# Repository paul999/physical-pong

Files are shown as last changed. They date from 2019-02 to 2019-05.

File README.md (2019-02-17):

# physical-pong

Do you remember pong from a long time ago? Well, I did, and I decided to make a physical version of the game.

This is the code required to run on the arduino mega. You can find more information about this project on the site: www.physical-pong.com

# Installing

This code is written for a arduino mega. You will need the platformio editor if you want to have it work out of the box.
It won't work with the default arduino IDE out of the box, and this is not something I plan on supporting.

If you are using this code without the ramps board as suggested, please make sure to check the pins in config.h, otherwise it won't work. For instructions on how to use the default configuration, please read the information found at https://www.physical-pong.com/instructions/
In config.php you can also enable DEBUG mode, which does write debug statements into the Serial console for debugging. It is suggested to disable this if you don't need it.

Before compiling, make sure you set the correct processor in paltformio.ini, otherwise you won't be able to upload your code to your Arduino.

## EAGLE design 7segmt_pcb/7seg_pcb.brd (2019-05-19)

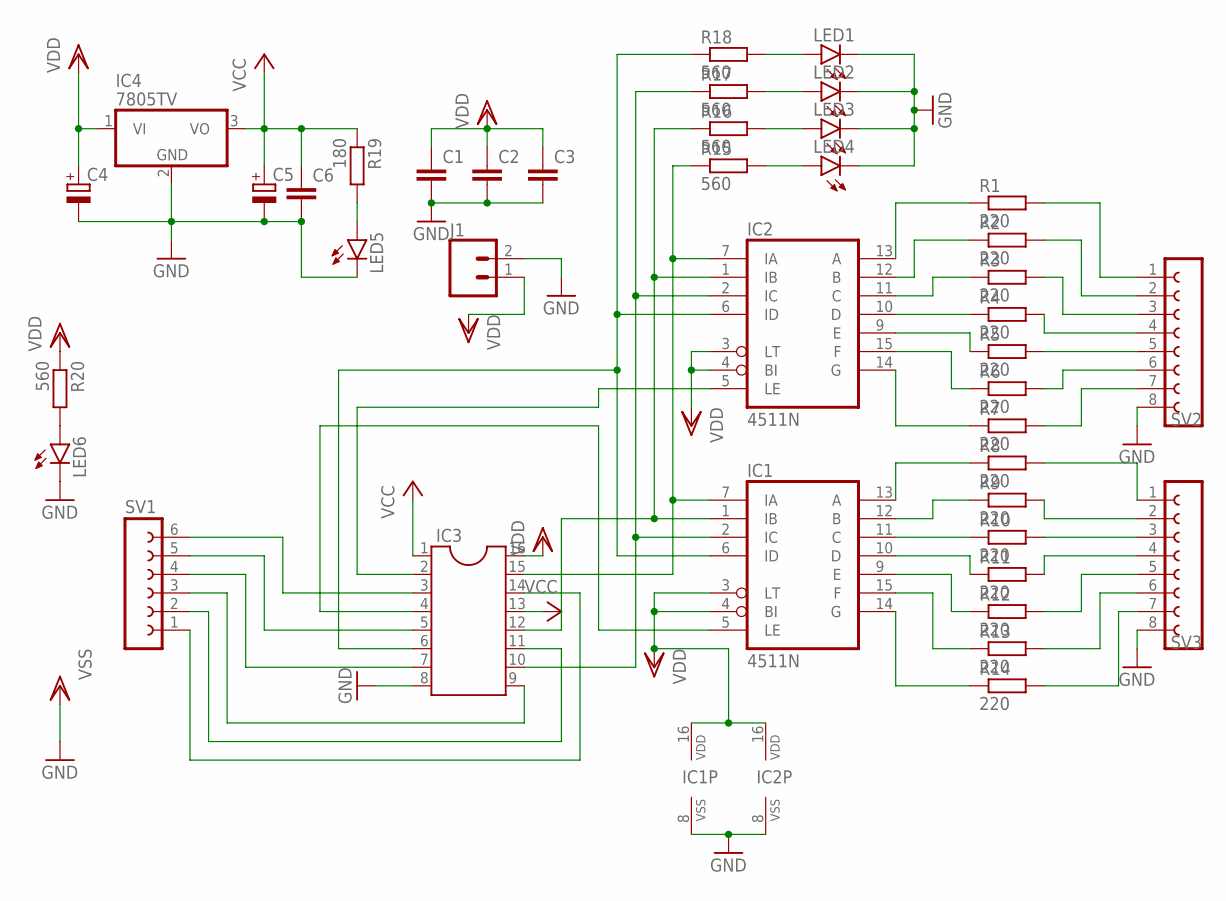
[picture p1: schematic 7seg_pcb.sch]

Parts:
C1, C2, C3, C6: C-EUC0805K; C0805K
C4, C5: CPOL-EUD; PANASONIC_D
IC1, IC2: 4511N; DIL16
IC3: DIL16S; SOCKET-16
IC4: 7805TV; TO220V
J1: CONN_025MM; SCREWTERMINAL-5MM-2
LED1, LED2, LED3, LED4, LED5, LED6: LEDCHIPLED_0805; CHIPLED_0805
R1, R2, R3, R4, R5, R6, R7, R8, R9, R10, R11, R12, R13, R14: 220; R0805
R15, R16, R17, R18, R20: 560; R0805
R19: 180; R0805
SV1: FE06-1; FE06
SV2, SV3: FE08-1; FE08

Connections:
GND: C1.2, C2.2, C3.2, C4.-, C5.-, C6.2, IC1.8 (VSS), IC2.8 (VSS), IC3.8, IC4.2 (GND), J1.2, LED1.C, LED2.C, LED3.C, LED4.C, LED5.C, LED6.C, SV2.8, SV3.8
unnamed: IC2.13 (A), R1.1
unnamed: IC2.12 (B), R2.1
unnamed: IC2.11 (C), R3.1
unnamed: IC2.10 (D), R4.1
unnamed: R14.2, SV3.7
unnamed: R13.2, SV3.6
unnamed: R12.2, SV3.5
unnamed: R11.2, SV3.4
unnamed: R10.2, SV3.3
unnamed: R9.2, SV3.2
unnamed: R8.2, SV3.1
unnamed: R7.2, SV2.7
unnamed: R6.2, SV2.6
unnamed: R5.2, SV2.5
unnamed: R4.2, SV2.4
unnamed: R3.2, SV2.3
unnamed: R2.2, SV2.2
unnamed: R1.2, SV2.1
unnamed: IC2.9 (E), R5.1
unnamed: IC2.15 (F), R6.1
unnamed: IC2.14 (G), R7.1
unnamed: IC1.13 (A), R8.1
unnamed: IC1.12 (B), R9.1
unnamed: IC1.11 (C), R10.1
unnamed: IC1.10 (D), R11.1
unnamed: IC1.9 (E), R12.1
unnamed: IC1.15 (F), R13.1
unnamed: IC1.14 (G), R14.1
unnamed: IC1.7 (IA), IC2.7 (IA), IC3.15, R15.1
unnamed: LED1.A, R18.2
unnamed: IC1.1 (IB), IC2.1 (IB), IC3.12, R16.1
unnamed: LED2.A, R17.2
unnamed: IC1.2 (IC), IC2.2 (IC), IC3.10, R17.1
unnamed: IC1.6 (ID), IC2.6 (ID), IC3.6, R18.1
unnamed: IC1.5 (LE), IC3.4
unnamed: IC3.3, SV1.6
unnamed: LED3.A, R16.2
unnamed: LED4.A, R15.2
unnamed: IC3.14, SV1.1
unnamed: IC3.11, SV1.2
unnamed: IC3.9, SV1.3
unnamed: IC3.7, SV1.4
unnamed: IC3.5, SV1.5
unnamed: LED5.A, R19.2
unnamed: IC2.5 (LE), IC3.2
unnamed: LED6.A, R20.2
VCC: C5.+, C6.1, IC3.1, IC3.13, IC4.3 (VO), R19.1
VDD: C1.1, C2.1, C3.1, C4.+, IC1.3 (LT), IC1.4 (BI), IC1.16 (VDD), IC2.3 (LT), IC2.4 (BI), IC2.16 (VDD), IC3.16, IC4.1 (VI), J1.1, R20.1

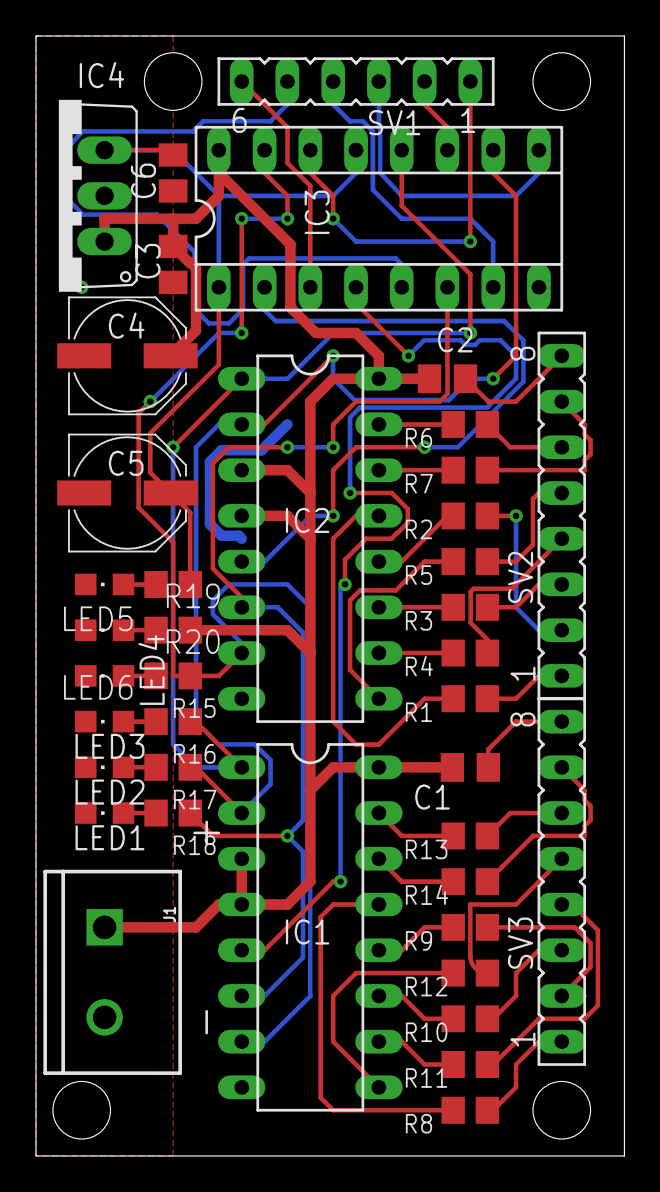
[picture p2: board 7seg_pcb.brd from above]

Board: 2 copper layers, 32.7 x 62.2 mm, 40 parts (0 on the bottom side), 49 nets.

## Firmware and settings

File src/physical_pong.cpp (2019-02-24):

/**
 * Copyright (C) 2019 by Paul Sohier
 * 
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
 * The above copyright notice and this permission notice shall be included in all copies or substantial portions of the Software.
 * 
 * THE SOFTWARE IS PROVIDED "AS IS", WITHOUT WARRANTY OF ANY KIND, EXPRESS OR IMPLIED, INCLUDING BUT NOT LIMITED TO THE WARRANTIES OF MERCHANTABILITY, 
 * FITNESS FOR A PARTICULAR PURPOSE AND NONINFRINGEMENT. IN NO EVENT SHALL THE AUTHORS OR COPYRIGHT HOLDERS BE LIABLE FOR ANY CLAIM, DAMAGES OR OTHER LIABILITY, 
 * WHETHER IN AN ACTION OF CONTRACT, TORT OR OTHERWISE, ARISING FROM, OUT OF OR IN CONNECTION WITH THE SOFTWARE OR THE USE OR OTHER DEALINGS IN THE SOFTWARE.
 */

#include "Arduino.h"
#include "config.h"
#include "motorControl.h"
#include "endstops.h"
#include "axis.h"
#include "log.h"

long player1_location = 0;
long player2_location = 0;
long short_axis_location = 0;
long long_axis_location = 0;
int mode = WAITING_FOR_START;
int current_long_direction = 0;
int current_short_direction = 0;

int short_last_change = 0;
int long_last_change = 0;
int steps_min_needed = 20; //ceil(STEPS_PER_MM * 3);

void setup()
{
  cli();
  Serial.begin(9600);
  logging("Starting up");
  setupPins();
  setupTimer();

  randomSeed(analogRead(0));

  logging("Startup done");

  disableMotor(false);

  logging("Going to start positions");

  player1_location = moveMotorToStart(aplayer1);
  player2_location = moveMotorToStart(aplayer2);

  logging("Moving axis");
  long_axis_location = moveMotorToStart(along);
  short_axis_location = moveMotorToStart(ashort);

  disableMotor(true);

  logging("Startup done. Now time to startup the loop");
}

void loop()
{
  if (mode == PLAYING)
  {
    digitalWrite(START_LED1, LOW);
    digitalWrite(START_LED2, LOW);
    // Time to do the actual movement.
    // But, only when we are still playing. (We might have just lost ;))
    if (mode == PLAYING)
    {
      movement mv;
      mv.along = HIGH;
      mv.ashort = HIGH;
      mv.aplayer1 = LOW;
      mv.aplayer2 = LOW;

      digitalWrite(LONG_AXIS_DIR, current_long_direction);
      digitalWrite(SHORT_AXIS_DIR, current_short_direction);
      int p1 = 0;
      int p2 = 0;

      if (digitalRead(PLAYER1_LEFT) == HIGH && readStop(aplayer1, start) == MISSED)
      {
        digitalWrite(PLAYER1_DIR, HIGH);
        mv.aplayer1 = HIGH;
        p1 = -1;
      }
      else if (digitalRead(PLAYER1_RIGHT) == HIGH && readStop(aplayer1, end) == MISSED)
      {
        digitalWrite(PLAYER1_DIR, LOW);
        mv.aplayer1 = HIGH;
        p1 = 1;
      }

      if (digitalRead(PLAYER2_LEFT) == HIGH && readStop(aplayer2, end) == MISSED)
      {
        digitalWrite(PLAYER2_DIR, LOW);
        mv.aplayer2 = HIGH;
        p2 = 1;
      }
      else if (digitalRead(PLAYER2_RIGHT) == HIGH && readStop(aplayer2, start) == MISSED)
      {
        digitalWrite(PLAYER2_DIR, HIGH);
        mv.aplayer2 = HIGH;
        p2 = -1;
      }
      moveSeveralMotorsOneStep(mv);

      player1_location = player1_location + p1;
      player2_location = player2_location + p2;
      long_axis_location = long_axis_location + (current_long_direction == HIGH ? 1 : -1);
      short_axis_location = short_axis_location + (current_short_direction == HIGH ? 1 : -1);

      // Check some of the locations we are at. We don't want negative locations and stuff.
      if (long_axis_location < 0)
      {
        long_axis_location = 0;
        logging("Warn: long axis went to < 0");
      }
      if (short_axis_location < 0)
      {
        short_axis_location = 0;
        logging("Warn: short axis went to < 0");
      }
      long_last_change++;
      if (long_last_change >= steps_min_needed)
      {
        if (readStop(along, start) == HIT || readStop(along, end) == HIT)
        {
          current_long_direction = current_long_direction == HIGH ? LOW : HIGH;
          logging("Something hit (LONG). Turning");
          long_last_change = 0;
        }
      }
      short_last_change++;
      if (short_last_change >= steps_min_needed)
      {
        if (readStop(ashort, start) == HIT || readStop(ashort, end) == HIT)
        {
          current_short_direction = current_short_direction == HIGH ? LOW : HIGH;
          logging("Something hit (SHORT). Turning");
          short_last_change = 0;
        }
      }

      if (readStop(aplayer1, start))
      {
        player1_location = 0;
      }
      if (readStop(aplayer2, start))
      {
        player2_location = 0;
      }
      if (player1_location < 0)
      {
        // We are at the begin. Set the location to 0
        player1_location = 0;
        logging("Warn: player1 axis went to < 0");
      }
      if (player2_location < 0)
      {
        // We are at the begin. Set the location to 0
        player2_location = 0;
        logging("Warn: player2 axis went to < 0");
      }
    }
  }
  else
  {
    digitalWrite(START_LED1, HIGH);
    digitalWrite(START_LED2, HIGH);

    if (digitalRead(START_BUTTON1) == HIGH || digitalRead(START_BUTTON2) == HIGH)
    {
      digitalWrite(START_LED1, LOW);
      digitalWrite(START_LED2, LOW);
      logging("User wants to start playing");
      mode = PLAYING;

      disableMotor(false);

      // Lets first move to start to get a good base point
      logging("Going to start now.");
      player1_location = moveMotorToStart(aplayer1);
      player2_location = moveMotorToStart(aplayer2);

      long_axis_location = moveMotorToStart(along);
      short_axis_location = moveMotorToStart(ashort);

      logging("Going to center position.");

      long loc = (PLAYER_LENGTH - (PLAYER_SIZE / 2l)) * STEPS_PER_MM;
      player1_location = moveMotorToLocation(aplayer1, loc, player1_location);
      player2_location = moveMotorToLocation(aplayer2, loc, player2_location);

      loc = (LONG_AXIS_LENGTH - (BLOCK_SIZE / 2l)) * STEPS_PER_MM;
      long_axis_location = moveMotorToLocation(along, loc, long_axis_location);

      loc = (SHORT_AXIS_LENGTH - (BLOCK_SIZE / 2l)) * STEPS_PER_MM;
      short_axis_location = moveMotorToLocation(ashort, loc, short_axis_location);

      // Decide to which directory we go to
      current_long_direction = (random(0, 500) % 2 == 0) ? HIGH : LOW;
      current_short_direction = (random(0, 500) % 2 == 0) ? HIGH : LOW;
      short_last_change = 0;
      long_last_change = 0;

      digitalWrite(LONG_AXIS_DIR, current_long_direction);
      digitalWrite(SHORT_AXIS_DIR, current_short_direction);

      disableMotor(true);
      // Lets get starting with warning the user that we are about to start ;)
      logging("Init done. Now lets warn the user");
      for (int i = 0; i < 10; i++)
      {
        digitalWrite(START_LED1, (i % 2 == 0) ? HIGH : LOW);
        digitalWrite(START_LED2, (i % 2 == 0) ? HIGH : LOW);
        delay(250);
      }
      digitalWrite(START_LED1, LOW);
      digitalWrite(START_LED2, LOW);
      disableMotor(false);
      logging("Lets get started");
    }
  }
}

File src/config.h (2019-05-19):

/**
 * Copyright (C) 2019 by Paul Sohier
 * 
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
 * The above copyright notice and this permission notice shall be included in all copies or substantial portions of the Software.
 * 
 * THE SOFTWARE IS PROVIDED "AS IS", WITHOUT WARRANTY OF ANY KIND, EXPRESS OR IMPLIED, INCLUDING BUT NOT LIMITED TO THE WARRANTIES OF MERCHANTABILITY, 
 * FITNESS FOR A PARTICULAR PURPOSE AND NONINFRINGEMENT. IN NO EVENT SHALL THE AUTHORS OR COPYRIGHT HOLDERS BE LIABLE FOR ANY CLAIM, DAMAGES OR OTHER LIABILITY, 
 * WHETHER IN AN ACTION OF CONTRACT, TORT OR OTHERWISE, ARISING FROM, OUT OF OR IN CONNECTION WITH THE SOFTWARE OR THE USE OR OTHER DEALINGS IN THE SOFTWARE.
 */

#ifndef __CONFIG_H__
#define __CONFIG_H__

// Enable debug mode. Will write stuff to serial for debugging
#define DEBUG false

// Enable calculation debug mode. Not suggested to enable, as it will cause
// issues with movements. Only enable it if you want to debug movement calculations
// Please note that enabling this flag will require you to press start when 
// the puck arrives at a start/stop on the long axis. 
// Make sure to read the serial output for information about the calculations and status!
#define DEBUG_CALC false

// Move to the start after a player is dead.
#define MOVE_TO_START true

// Shaft length for player/axis
// Make sure these sizes are correct, as they are used for a lot of calculations!
#define PLAYER_LENGTH 280
#define LONG_AXIS_LENGTH 480
#define SHORT_AXIS_LENGTH 280
#define STEPS_PER_MM 5

// Define the number of MM that is used for dead calculations.
#define MM_CALC 10

// Max number of games before we end
#define MAX_GAMES 10

// Begin/end stops for player bars
// X
#define PLAYER1_BEGIN   3
#define PLAYER1_END     2
// Z
#define PLAYER2_BEGIN   18
#define PLAYER2_END     19

// Begin/end stops for axis
// y
#define LONG_AXIS_BEGIN   14
#define LONG_AXIS_END     15
// AUX 2
#define SHORT_AXIS_BEGIN  16//65
#define SHORT_AXIS_END    17//66

// Motor settings for players
// X
#define PLAYER1_DIR   55//55
#define PLAYER1_STEP  54//54
#define PLAYER1_EN    38//38
// Y
#define PLAYER2_DIR   61//61
#define PLAYER2_STEP  60//60
#define PLAYER2_EN    56//56

// Motor settings for axis
// Z
#define LONG_AXIS_DIR   48
#define LONG_AXIS_STEP  46
#define LONG_AXIS_EN    62
// E
#define SHORT_AXIS_DIR  28
#define SHORT_AXIS_STEP 26
#define SHORT_AXIS_EN   24

// Buttons for going left/right with player pad
#define PLAYER1_LEFT  23
#define PLAYER1_RIGHT 25
#define PLAYER2_LEFT  27
#define PLAYER2_RIGHT 29    	

// Start button + start LED in button (Will light on when no game is active)
// Aux 1
#define START_BUTTON1  57
#define START_BUTTON2  58
// Heatbed connector
#define START_LED1     9
#define START_LED2     10

// Size of the player (Only width) blocks and actual block. Please keep in mind that the block should be square.
// Only change if you changed the 3D printed parts!
#define PLAYER_SIZE 45
#define BLOCK_SIZE 25

// Enable two 7 segment displays showing the current score. Make sure to set the correct pints below
#define ENABLE_SCORE_DISPLAY true
#define SEGMENT_A_PIN 31
#define SEGMENT_B_PIN 33
#define SEGMENT_C_PIN 35
#define SEGMENT_D_PIN 37
#define PLAYER1_LATCH_PIN 39
#define PLAYER2_LATCH_PIN 41

// Do not change after this line
#define PLAYING 1
#define WAITING_FOR_START 2
#define RESTARTING 3

#endif

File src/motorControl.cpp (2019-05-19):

/**
   Copyright (C) 2019 by Paul Sohier

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
   The above copyright notice and this permission notice shall be included in all copies or substantial portions of the Software.

   THE SOFTWARE IS PROVIDED "AS IS", WITHOUT WARRANTY OF ANY KIND, EXPRESS OR IMPLIED, INCLUDING BUT NOT LIMITED TO THE WARRANTIES OF MERCHANTABILITY,
   FITNESS FOR A PARTICULAR PURPOSE AND NONINFRINGEMENT. IN NO EVENT SHALL THE AUTHORS OR COPYRIGHT HOLDERS BE LIABLE FOR ANY CLAIM, DAMAGES OR OTHER LIABILITY,
   WHETHER IN AN ACTION OF CONTRACT, TORT OR OTHERWISE, ARISING FROM, OUT OF OR IN CONNECTION WITH THE SOFTWARE OR THE USE OR OTHER DEALINGS IN THE SOFTWARE.
*/

#include "Arduino.h"
#include "log.h"
#include "config.h"
#include "endstops.h"
#include "axis.h"
#include "motorControl.h"

int moveSequence(axis moveAxis)
{
  digitalWrite(getPin(stepPin, moveAxis), HIGH);
  delayMicroseconds(400);
  digitalWrite(getPin(stepPin, moveAxis), LOW);
  delayMicroseconds(400);

  if (readStop(moveAxis, end))
  {
    // Huh, we did hit a end?
    logging("We did hit a endstop?");
    return 1;
  }
  if (readStop(moveAxis, start))
  {
    logging("We did hit a start");
    return -1;
  }

  return 0;
}
void disableMotor(bool status)
{
  int st = status ? HIGH : LOW;
  digitalWrite(PLAYER1_EN, st);
  digitalWrite(PLAYER2_EN, st);
  digitalWrite(LONG_AXIS_EN, st);
  digitalWrite(SHORT_AXIS_EN, st);
}

long moveMotorToStart(axis moveAxis)
{
  if (readStop(moveAxis, start) == HIT)
  {
    // Motor is already in start Position.
    logging("Motor is at start");
    return 0;
  }
  digitalWrite(getPin(dirPin, moveAxis), HIGH);
  boolean atEnd = false;
  if (readStop(moveAxis, end) == HIT)
  {
    logging("Motor is at end");
    atEnd = true;
  }
  logging("Starting loop");

  long i = 0;

  while (true)
  {
    i++;
    if (i > 100000l)
    {
      // 200 steps per mm, max length is ~500mm. So 200 * 500: 100000 should always result in the start!
      logging("Unable to get to start");
      disableMotor(true);
      return -1;
    }
    if (!atEnd && readStop(moveAxis, end) == HIT)
    {
      logging("Looks like we hit a endstop while going to home. Wrongly configured?");
      logging("We will return now, but we are not in a save position!");
      disableMotor(true);
      return -1;
    }
    if (atEnd && readStop(moveAxis, end) == MISSED)
    {
      atEnd = false;
    }
    if (readStop(moveAxis, start) == HIT)
    {
      logging("Arrived at start :D");
      return 0;
    }
    digitalWrite(getPin(stepPin, moveAxis), HIGH);
    delayMicroseconds(400);
    digitalWrite(getPin(stepPin, moveAxis), LOW);
    delayMicroseconds(400);
  }
}

long moveMotorToLocation(axis moveAxis, long location, long currentLocation)
{
  logging("Moving to location");
  if (location == currentLocation)
  {
    return currentLocation;
  }
  if (location <= currentLocation)
  {
    digitalWrite(getPin(dirPin, moveAxis), HIGH);
  }
  else
  {
    digitalWrite(getPin(dirPin, moveAxis), LOW);
  }
  bool isStart = readStop(moveAxis, start) == HIT;
  bool isStop = readStop(moveAxis, end) == HIT;

  long newCurrent = currentLocation;

  long diff = location - currentLocation;

  if (diff < 0)
  {
    diff *= -1;
    for (long i = 0; i < diff; i++)
    {
      // First check if the start values are true,
      // otherwise we do an unneeded call to readStop
      if (isStart && readStop(moveAxis, start) == MISSED)
      {
        isStart = false;
      }
      if (isStop && readStop(moveAxis, end) == MISSED)
      {
        isStop = false;
      }
      newCurrent += 1;
      int result = moveSequence(moveAxis);
      switch (result)
      {
      case -1:
        if (!isStart)
        {
          // Only return if we didn't start at start.
          logging("Returning 0");
          return 0; // Start
        }
        break;
      case 1:
        if (!isStop)
        {
          // Only return if we didn't start at end.
          logging("Hit end?");
          return newCurrent; // TODO: Check correct value.
        }
        break;
      }
    }
  }
  else
  {
    for (long i = 0; i < diff; i++)
    {
      // First check if the start values are true,
      // otherwise we do an unneeded call to readStop
      if (isStart && readStop(moveAxis, start) == MISSED)
      {
        isStart = false;
      }
      if (isStop && readStop(moveAxis, end) == MISSED)
      {
        isStop = false;
      }
      newCurrent += 1;
      int result = moveSequence(moveAxis);

      switch (result)
      {
      case -1:
        if (!isStart)
        {
          // Only return if we didn't start at start.
          logging("Returning 0");
          return 0; // Start
        }
        break;
      case 1:
        if (!isStop)
        {
          // Only return if we didn't start at end.
          logging("Hit end?");
          return newCurrent; // TODO: Check correct value.
        }
        break;
      }
    }
  }
  return newCurrent;
}

void moveSeveralMotorsOneStep(movement mv)
{
  digitalWrite(getPin(stepPin, along), mv.along);
  digitalWrite(getPin(stepPin, ashort), mv.ashort);
  digitalWrite(getPin(stepPin, aplayer1), mv.aplayer1);
  digitalWrite(getPin(stepPin, aplayer2), mv.aplayer2);
  delayMicroseconds(400);
  digitalWrite(getPin(stepPin, along), LOW);
  digitalWrite(getPin(stepPin, ashort), LOW);
  digitalWrite(getPin(stepPin, aplayer1), LOW);
  digitalWrite(getPin(stepPin, aplayer2), LOW);
  delayMicroseconds(400);
}

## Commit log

2019-01-19 Add basic files for arduino code
2019-02-06 Getting things started. Lots of fixes for motor control and stuff like that.
    [config.h, motorControl.cpp, physical_pong.cpp]
2019-02-22 Remove continues logging. It makes the arduino really slow. Change timings between movements. Set correct location pin
    [motorControl.cpp, physical_pong.cpp]
2019-02-23 Lot of changes to the code. Rewrite the way endstops and stuff are handled. Currently need to redo some of the stepper motor stuff, as due to the timer changing, it is now sort of borked (But it stil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
    [axis.cpp, endstops.cpp, motorControl.cpp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]
2019-02-24 Fixing a issue with pin init not working. Make sure to limit left/right buttons for players correctly. Some more cleanup
    [axis.cpp, endstops.cpp, motorControl.cpp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]
2019-03-23 Bunch of changes regarding the game. Please note that the dead/alive calculation is broken atm.
    [config.h, game.cpp, motorControl.cpp]
2019-05-19 Add support for 7 segment scoring display. Requires a bit of setup in config.h and enabling it before it works. Requires a seperate PCB the bitshifter and stuff. More info on it soon.
    Change the speed of the game a bit.
2019-05-19 Add 7 segment PCB
    [7seg_pcb.brd, 7seg_pcb.sch]

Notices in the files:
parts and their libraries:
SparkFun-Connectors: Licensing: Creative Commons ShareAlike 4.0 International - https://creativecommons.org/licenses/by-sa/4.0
